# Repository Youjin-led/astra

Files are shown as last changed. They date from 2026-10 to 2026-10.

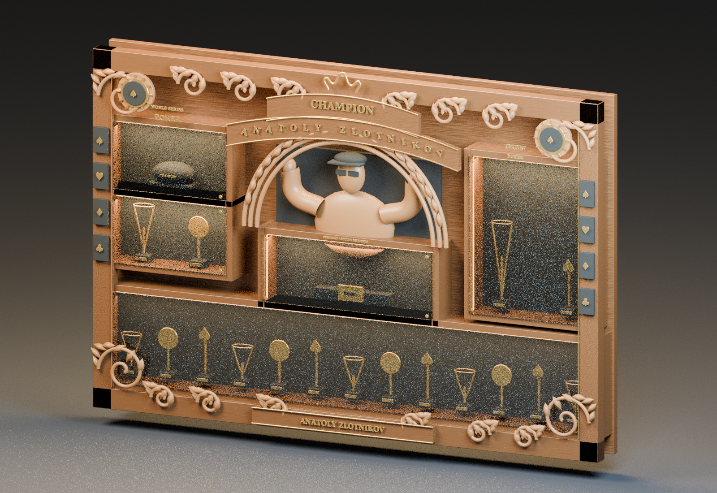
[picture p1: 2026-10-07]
design/astra_preview.png

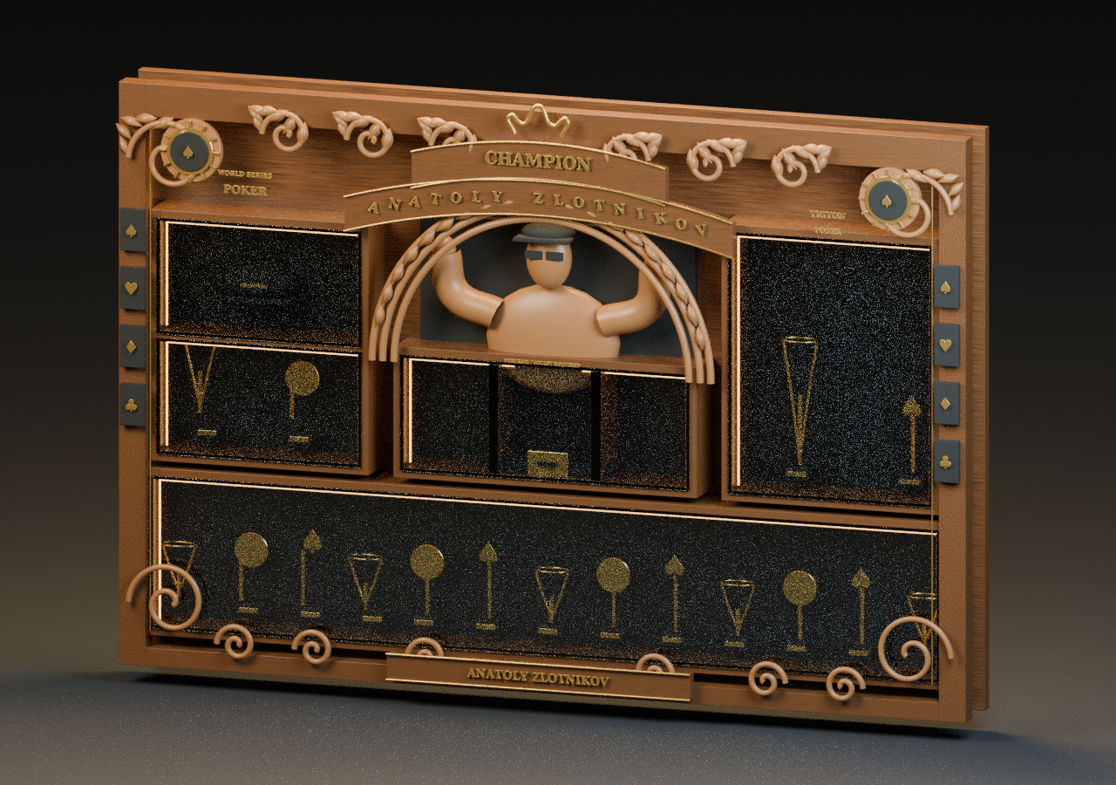
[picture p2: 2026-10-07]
project_v2/final_visual.png

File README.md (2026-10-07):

# ASTRA — витрина / инструкция по исходному референсу

Актуальная версия — инструкция с оригинальным изображением и его фрагментами из присланного ZIP:

- [Новый комплект — ZIP](https://github.com/Youjin-led/astra/raw/refs/heads/main/astra_reference_package.zip)
- [Новая инструкция — PDF, 24 страницы](https://github.com/Youjin-led/astra/raw/refs/heads/main/reference_project/assembly_from_reference_ru.pdf)
- [Описание и нерешённые размеры](reference_project/README.md)

Исходные размеры сохранены, включая нижнюю нишу 1160 × 200 мм. Для окончательного изготовления нужны уточнения, перечисленные в инструкции. Оригинальное изображение получено из ZIP и встроено: фасад, слои, детали и фрагменты для сборки.

---

## Архив предыдущей версии V2 (не актуальный образец внешнего вида)

## Скачать

- [Комплект для мастерской — ZIP](https://github.com/Youjin-led/astra/raw/refs/heads/main/astra_workshop_package.zip)
- [Инструкция сборки — PDF, 22 страницы](https://github.com/Youjin-led/astra/raw/refs/heads/main/project_v2/assembly_manual_ru.pdf)
- [Модель Blender с двумя сценами](https://github.com/Youjin-led/astra/raw/refs/heads/main/project_v2/astra_workshop_v2.blend)
- [Финальная визуализация](project_v2/final_visual.png)
- [Взрыв-схема слоёв](project_v2/exploded_layers.png)

В `project_v2` находятся спецификация 29 деталей, размерная разметка SVG/DXF, профили заготовок, раскрой и 11 этапов сборки. [Описание и ограничения версии](project_v2/README.md).

Это документация корпуса для прототипа. Перед окончательным раскроем нужны размеры экспонатов, подбор реальной фурнитуры и проверка крепления по стене и весу. Портрет, орнамент и надписи остаются эскизными; готовые траектории ЧПУ не включены. Нижний проём в V2 уменьшен до 1110 × 200 мм ради доступа к съёмной панели при общей ширине 1200 мм.

`design` содержит первую эскизную версию и материалы, используемые при воспроизведении V2.

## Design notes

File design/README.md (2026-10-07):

# ASTRA — эскиз витрины в Blender

Откройте `astra_display.blend` в Blender 4.3 или новее. `astra_preview.png` — рендер модели. `create_model.py` воспроизводит сцену командой:

```sh
blender -b -t 6 --python /workspace/astra/design/create_model.py
```

Единицы — миллиметры; координаты объектов в метрах. X — ширина, Z — высота, лицевая сторона направлена в −Y. Основная рама: 1200 × 800 мм. Корона выступает над ней примерно на 14 мм. Задняя панель 18 мм; внутренняя глубина ниш 70 мм; стенки коробов 15 мм; акрил 4 мм. Полная глубина с декоративными элементами около 120 мм: при выбранных толщинах уложиться в указанные на референсе 70–100 мм без переработки конструкции нельзя.

Коллекции разделяют заднюю панель, короба, декоративную резьбу, латунные надписи, акрил, LED, условные трофеи, условный портрет, крепление и студийную сцену. Объекты можно редактировать по отдельности. Орнамент процедурный; это интерпретация референса, а не точная копия.

Ниши: две левые 280 × 150 мм, центральная 400 × 150 мм, правая вертикальная 280 × 350 мм, нижняя 1160 × 200 мм. Правая вертикальная ниша объединена: референс неоднозначен в расположении правой средней секции. LED — визуализация тёплой подсветки, не электрическая схема. Акрил смоделирован прозрачным материалом с отдельными условными магнитами.

## Перед изготовлением

Это концептуальная модель, не готовые траектории ЧПУ или конструкторская документация. Портрет и экспонаты заменены объёмными заглушками. Для точного портрета нужны фотографии/скан; для посадки экспонатов — их размеры. Логотипы заменены текстовыми обозначениями. Для производства требуется уточнить орнамент, проверить замкнутость и технологичность деталей, радиусы фрез, зазоры, раскрой и прочность крепления. Указанная на картинке нагрузка 40–50 кг расчётом не подтверждена. Верхняя планка French cleat пока прямоугольная: угол и крепёж должны быть спроектированы отдельно.

Из-за перспективы и противоречий размеров на исходном изображении некоторые расположения выбраны эскизно. Надписи, ниши и детали должны быть согласованы перед выпуском рабочих файлов.

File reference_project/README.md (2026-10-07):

# ASTRA — инструкция по исходным изображениям

Эта версия создана заново по композиции и надписям на присланном референсе. Предыдущая модель Blender и размеры версии V2 не использованы.

## Файлы

- `assembly_from_reference_ru.pdf` — 24 страницы: исходные размеры, схема расположения, слои, перечень деталей, формулы коробов, узлы акрила / LED и 11 шагов сборки.
- `reference_dimensions.csv` — все шесть строк исходной таблицы размеров, открывается в Excel (UTF-8, разделитель `;`).
- `reference_dimensions.json` — сведения с изображения; неизвестные координаты оставлены пустыми.
- `reference_facade_preview.png` — предварительный просмотр страницы PDF с исходным фасадом.
- `measurements_template.csv` — бланк замеров экспонатов для мастера.
- `create_reference_manual.py` — генератор PDF; использует Python и ReportLab, без Blender.

Сохранены основной габарит 1200 × 800 мм и нижняя ниша 1160 × 200 × 70 мм. Стенки коробов 15–18 мм и слой дерева 30–40 мм оставлены как варианты исходного референса, а не произвольно выбранные толщины.

## Что ещё нужно для мастерской

Референс не содержит координат всех проёмов, отдельных размеров малых боковых ячеек, однозначного положения правой средней ниши, точного разреза, параметров магнитов, крепежа и рельефа. Поэтому это инструкция и размерное техническое задание, **не окончательная карта раскроя или готовая программа ЧПУ**. Уточнения перечислены на последней странице.

При отдельном накладном слое дерева указанная глубина 70–100 мм противоречит пакету материалов. Необходимо согласовать разрез до изготовления. Нагрузка крепления из референса не подтверждена.

## Исходные фотографии

Оригинальное изображение получено из ZIP пользователя и сохранено в `source/08387e1d-4358-4564-9a3d-56a1dc0bfdc0.png`. На обложку и страницу результата помещён фасад; в разделы сборки — соответствующие фрагменты коробов, декора, LED, магнитного узла и крепления на стену. На последней странице исходный лист показан целиком.

Изображение встроено в PDF как один оригинал; отдельные фрагменты показаны через области обрезки при вёрстке. Генеративная перерисовка и прежние Blender-рендеры не используются. Дополнительные схемы формул коробов, материалов и соединений оставлены плоскими пояснениями.

Исходный лист содержит визуализацию проекта, а не подтверждение изготовленного изделия. Пиксельные пропорции не используются как точные производственные размеры.

## Повторное создание

```sh
python /workspace/astra/reference_project/create_reference_manual.py
```

Шрифты DejaVu встраиваются в PDF, инструкция читается на Windows без установки шрифтов.

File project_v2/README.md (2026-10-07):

# ASTRA V2 — комплект для мастерской

Начните с **assembly_manual_ru.pdf**: 22 страницы, детали с номерами, размеры, раскрой, слои и 11 этапов сборки. В **astra_workshop_v2.blend** те же номера A/L/R/C/B/D/G. **final_visual.png** — финальная визуализация этой версии; **exploded_layers.png** — взрыв-схема. В Blender есть две сцены: собранный корпус и разделённые слои. **parts.csv** открывается в Excel, разделитель `;`, кодировка UTF-8 с BOM.

## Что переработано

В референсе размеры местами противоречат друг другу. V2 — самостоятельная компоновка по мотивам референса, согласованная между таблицей деталей и корпусом Blender:

- Рама 1200 × 800 мм. Корона выступает выше основной рамы; итоговая высота с декором больше 800 мм.
- Задник 18 мм; стенки 15 мм; чистая глубина до плоскости акрила 70 мм; акрил 4 мм.
- Левые проёмы 280 × 150 мм, два, общая полка.
- Правый проём 280 × 350 мм; отдельная правая средняя ниша не добавлена, поскольку в референсе её расположение неоднозначно.
- Центральный проём 400 × 150 мм с тремя ячейками 120 / 130 / 120 мм и двумя перегородками 15 мм.
- Нижний проём **1110 × 200 мм** вместо 1160 × 200 из референса. Это оставляет место для бокового декора и снятия акрила в раме шириной 1200 мм.
- Съёмные панели акрила накладные; нахлёст 5 мм. Боковые декоративные планки сужены до 38 мм. Между нижней панелью и планками номинально 2 мм с каждой стороны; проверить фактическую толщину/геометрию и зазоры до резки акрила.
- Базовый пакет 92 мм; выступающий декор и настенное крепление увеличивают общую глубину.

## Файлы для мастерской

`drawings/front_layout.svg` и `.dxf` — фронтальная разметка в миллиметрах, без траекторий резания и карты сверления. SVG содержит контрольную линейку 100 мм. Перед печатью/импортом проверить масштаб.

`drawings/*_blank.svg` — прямоугольные профили всех заготовок 1:1, **без отверстий, рельефа и технологических припусков**. Это не программы ЧПУ. Для деталей фанеры 15 мм показан широкий профиль полосы 70 мм.

`cut_plan.json` — раскрой полос 70 мм из листа 2440 × 1220 мм, расчётный пропил 3 мм. Пересчитать для фактической пилы и размера листа. `parts.json` — полный источник геометрии корпуса.

## Что нужно решить до изготовления

Комплект ещё **не утверждён для серийного или окончательного изготовления**. Сначала измерить экспонаты (особенно их глубину), выбрать породу дерева, реальные магниты/площадки и отделку, проверить прогиб длинной полки, утвердить крепёж по материалу стены и полному весу.

Резьба, портрет, логотипы, корона, надписи и трофеи — визуальные эскизы из первой модели. Их объекты помечены `CONCEPT`; они не входят в 29 прямоугольных деталей корпуса и не являются готовым комплектом ЧПУ. Орнаменты нужно переработать так, чтобы они не перекрывали снятие акрила и зоны крепежа. Нижняя резьба частично убрана из визуализации для доступа к нижней панели.

French cleat в Blender — схема расположения, а не проверенная пара сопряжённых деталей или расчёт крепежа. Две заготовки 1000 × 40 × 18 мм указаны отдельно в материалах; точный скос, сопряжение и анкеры определяет мастер после осмотра стены. Нагрузка 40–50 кг из картинки не подтверждена.

## Воспроизведение

Blender 4.3+, Python 3 с ReportLab. Запускать в существующей рабочей копии; отдельный worktree не нужен. Сохраните папку `design`: из неё загружаются исходные материалы и эскизный декор.

```sh
blender -b -t 6 --python /workspace/astra/project_v2/build_blender.py
blender -b /workspace/astra/project_v2/astra_workshop_v2.blend -t 6 --python /workspace/astra/project_v2/make_exploded.py
python /workspace/astra/project_v2/make_documents.py
python /workspace/astra/project_v2/validate_project.py
```

PDF генерируется после визуализации, чтобы новый рендер попал на обложку. Все размеры корпуса задаются в `project_data.py`.

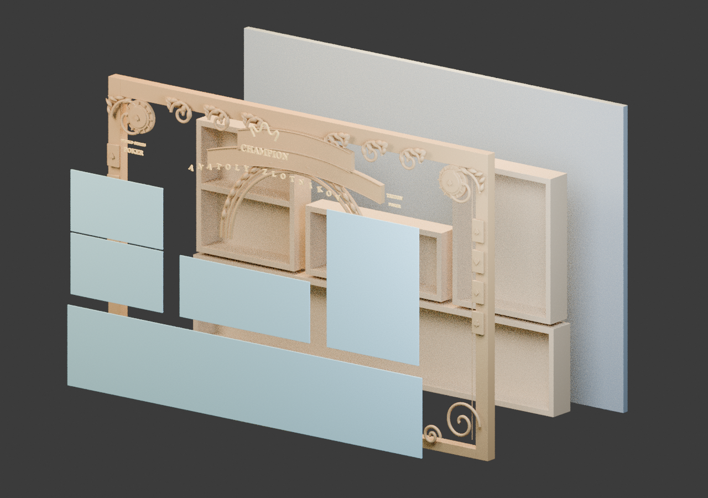
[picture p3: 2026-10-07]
project_v2/exploded_layers.png

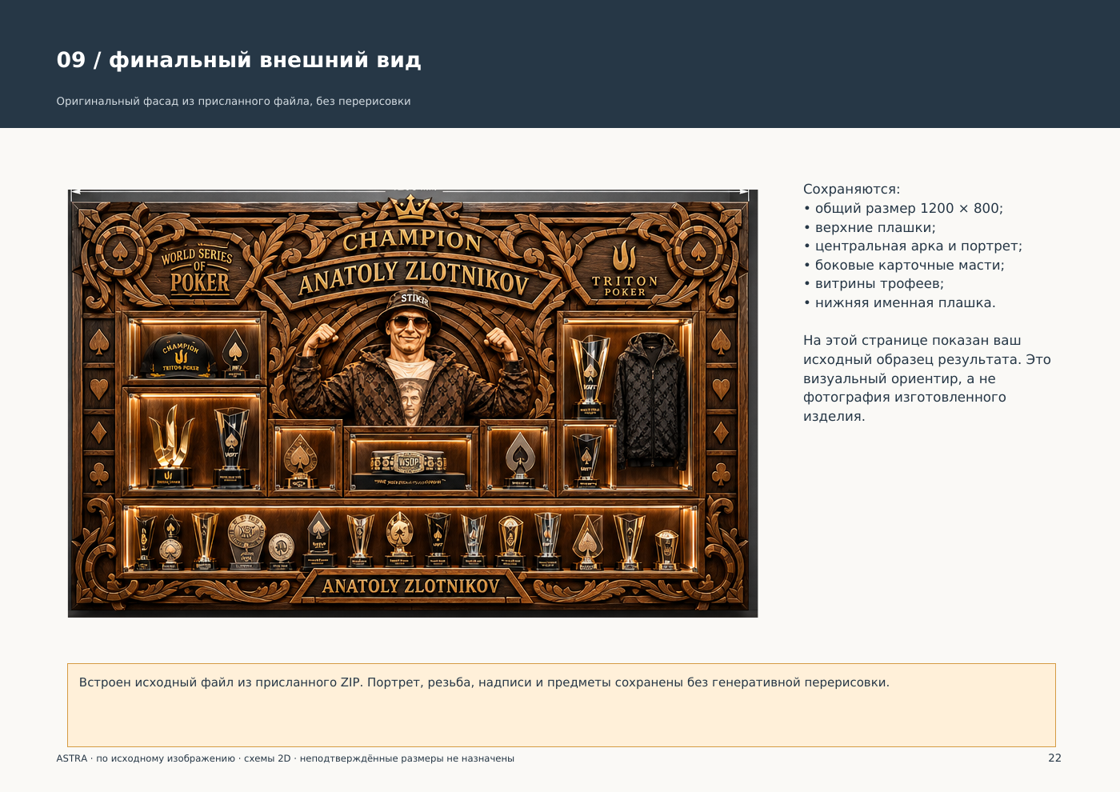
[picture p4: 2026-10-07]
reference_project/reference_facade_preview.png

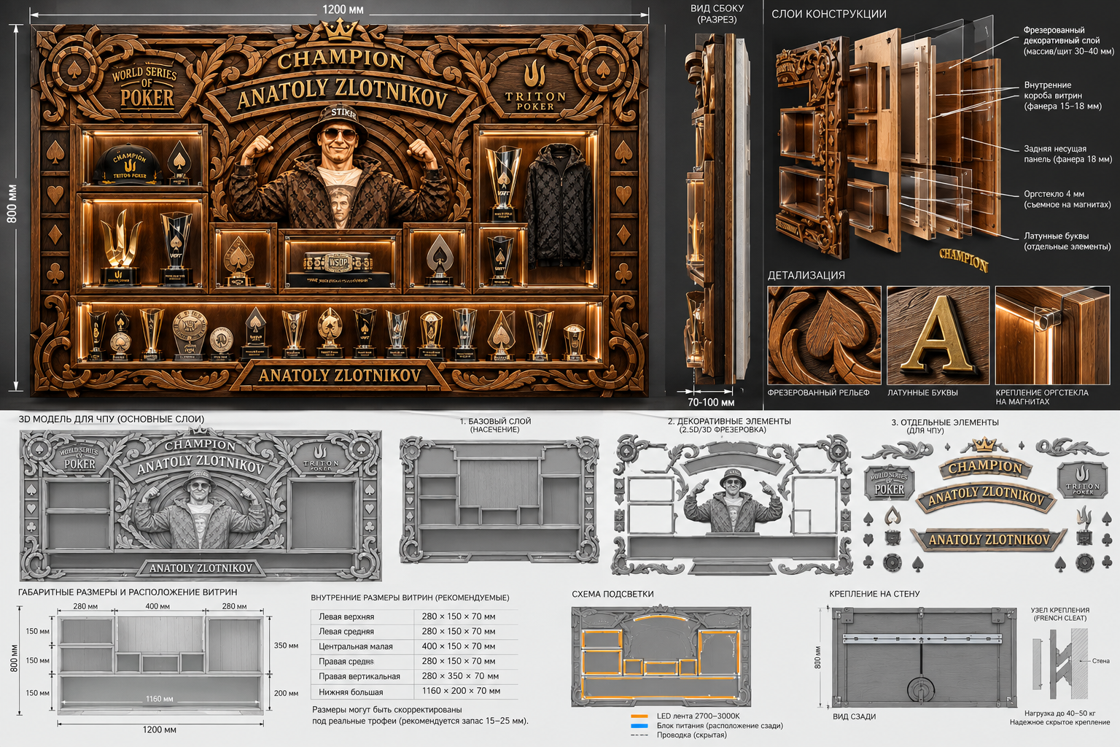
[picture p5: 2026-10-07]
reference_project/source/08387e1d-4358-4564-9a3d-56a1dc0bfdc0.png

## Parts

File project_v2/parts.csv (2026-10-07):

ID | Наименование | Материал | X мм | Y мм | Z мм | Центр X мм | Центр Y мм | Центр Z мм | Этап | Примечание
A01 | Задняя панель | Фанера 18 | 1200 | 18 | 800 | 0 | 9 | 400 | 1
L01 | Боковина левого блока | Фанера 15 | 15 | 70 | 345 | -552.5 | -35 | 452.5 | 2
L02 | Боковина левого блока | Фанера 15 | 15 | 70 | 345 | -257.5 | -35 | 452.5 | 2
L03 | Полка левого блока | Фанера 15 | 280 | 70 | 15 | -405 | -35 | 287.5 | 2
L04 | Полка левого блока | Фанера 15 | 280 | 70 | 15 | -405 | -35 | 452.5 | 2
L05 | Полка левого блока | Фанера 15 | 280 | 70 | 15 | -405 | -35 | 617.5 | 2
R01 | Боковина правого блока | Фанера 15 | 15 | 70 | 380 | 257.5 | -35 | 470 | 3
R02 | Боковина правого блока | Фанера 15 | 15 | 70 | 380 | 552.5 | -35 | 470 | 3
R03 | Полка правого блока | Фанера 15 | 280 | 70 | 15 | 405 | -35 | 287.5 | 3
R04 | Полка правого блока | Фанера 15 | 280 | 70 | 15 | 405 | -35 | 652.5 | 3
C01 | Боковина центрального блока | Фанера 15 | 15 | 70 | 180 | -207.5 | -35 | 370 | 4
C02 | Боковина центрального блока | Фанера 15 | 15 | 70 | 180 | 207.5 | -35 | 370 | 4
C03 | Полка центрального блока | Фанера 15 | 400 | 70 | 15 | 0 | -35 | 287.5 | 4
C04 | Полка центрального блока | Фанера 15 | 400 | 70 | 15 | 0 | -35 | 452.5 | 4
C05 | Перегородка центрального блока | Фанера 15 | 15 | 70 | 150 | -72.5 | -35 | 370 | 4
C06 | Перегородка центрального блока | Фанера 15 | 15 | 70 | 150 | 72.5 | -35 | 370 | 4
B01 | Боковина нижнего блока | Фанера 15 | 15 | 70 | 230 | -562.5 | -35 | 155 | 5
B02 | Боковина нижнего блока | Фанера 15 | 15 | 70 | 230 | 562.5 | -35 | 155 | 5
B03 | Полка нижнего блока | Фанера 15 | 1110 | 70 | 15 | 0 | -35 | 47.5 | 5 | Под нагрузкой проверить прогиб; при необходимости добавить опору.
B04 | Полка нижнего блока | Фанера 15 | 1110 | 70 | 15 | 0 | -35 | 262.5 | 5 | Под нагрузкой проверить прогиб; при необходимости добавить опору.
D01 | Боковая декоративная планка | Дерево 30 | 38 | 30 | 800 | -581 | -67 | 400 | 7 | Резьба эскизная; заготовка, не готовый рельеф ЧПУ.
D02 | Боковая декоративная планка | Дерево 30 | 38 | 30 | 800 | 581 | -67 | 400 | 7 | Резьба эскизная; заготовка, не готовый рельеф ЧПУ.
D03 | Нижняя декоративная планка | Дерево 30 | 1124 | 30 | 25 | 0 | -67 | 12.5 | 7
D04 | Верхняя декоративная планка | Дерево 30 | 1124 | 30 | 45 | 0 | -67 | 777.5 | 7
G01 | Левая нижняя панель | Акрил 4 | 290 | 4 | 160 | -405 | -72 | 370 | 8 | Накладная панель: нахлёст 5 мм на каждую сторону; проверить шаблоном.
G02 | Левая верхняя панель | Акрил 4 | 290 | 4 | 160 | -405 | -72 | 535 | 8 | Накладная панель: нахлёст 5 мм на каждую сторону; проверить шаблоном.
G03 | Центральная панель | Акрил 4 | 410 | 4 | 160 | 0 | -72 | 370 | 8 | Накладная панель: нахлёст 5 мм на каждую сторону; проверить шаблоном.
G04 | Правая панель | Акрил 4 | 290 | 4 | 360 | 405 | -72 | 470 | 8 | Накладная панель: нахлёст 5 мм на каждую сторону; проверить шаблоном.
G05 | Нижняя панель | Акрил 4 | 1120 | 4 | 210 | 0 | -72 | 155 | 8 | Накладная панель: нахлёст 5 мм на каждую сторону; проверить шаблоном.

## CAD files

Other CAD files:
project_v2/drawings/front_layout.dxf
design/astra_display.blend
project_v2/astra_workshop_v2.blend

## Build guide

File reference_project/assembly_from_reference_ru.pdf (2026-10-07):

## ASTRA / сборка по референсу

Оригинальное изображение, детали из референса и пошаговые пояснения

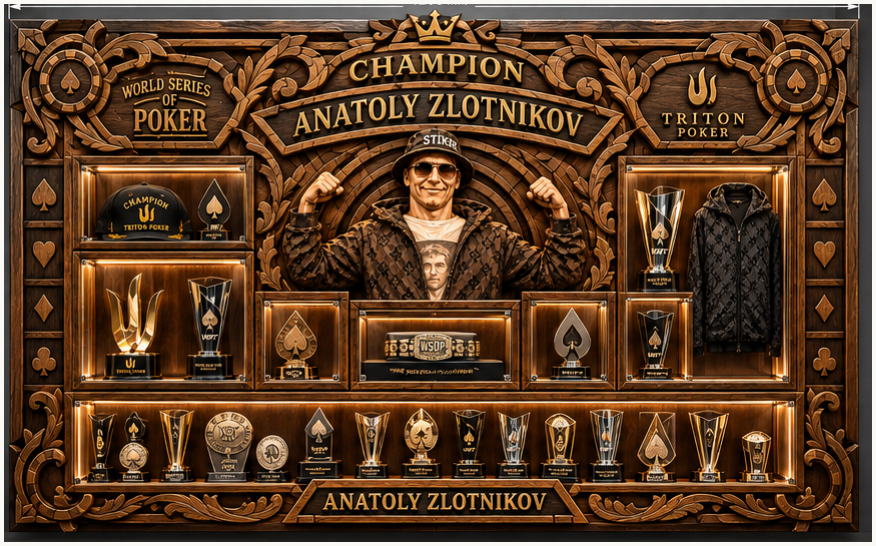
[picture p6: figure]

ASTRA · по исходному изображению · схемы 2D · неподтверждённые размеры не назначены | 1

В комплекте:
- исходные размеры;
- схема конструкции;
- перечень деталей;
- 11 этапов сборки;
- узлы акрила и LED.

Иллюстрации взяты из вашего файла. Резьба, портрет и
исходная композиция
сохранены. Дополнительные
схемы объясняют узлы сборки.

На обложке — фрагмент вашего исходного изображения. Разделение на детали показано далее теми же изображениями из референса.

## 01 / что зафиксировано на изображении

Миллиметры; сведения перенесены из исходного референса

ASTRA · по исходному изображению · схемы 2D · неподтверждённые размеры не назначены | 2
Параметр | Значение | Статус
Основной габарит | 1200 × 800 | Указано на изображении
Общая глубина | 70–100 | Указано; требует согласования слоёв
Задняя панель | Фанера 18 | Указано
Короба | Фанера 15–18 | Толщину нужно выбрать
Декоративный слой | Дерево / щит 30–40 | Указано; рельеф отдельно
Прозрачные панели | Акрил 4 | Указано
Надписи | Латунь, отдельные элементы | Толщина и контуры не заданы
Подсветка | LED 2700–3000 K | Питание и мощность не заданы
Настенное крепление | French cleat | Нагрузка и анкеры не подтверждены

Размер 1200 × 800 относится к основному прямоугольному корпусу. Включена ли выступающая корона в общий габарит — уточнить. Пропорции на картинке не заменяют координаты установки коробов и точные контуры резьбы.

## 02 / расположение витрин

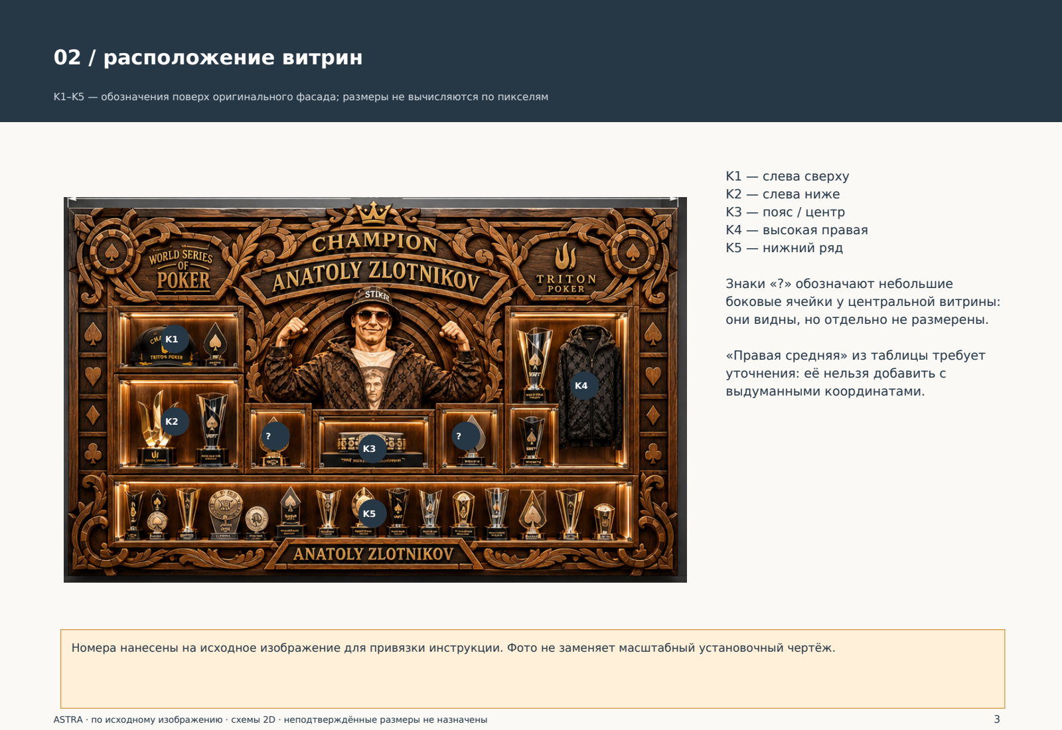
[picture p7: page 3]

K1–K5 — обозначения поверх оригинального фасада; размеры не вычисляются по пикселям

ASTRA · по исходному изображению · схемы 2D · неподтверждённые размеры не назначены | 3

K1

K2

K3

K4

K5

? | ?

K1 — слева сверху
K2 — слева ниже
K3 — пояс / центр
K4 — высокая правая
K5 — нижний ряд

Знаки «?» обозначают небольшие боковые ячейки у центральной витрины: они видны, но отдельно не размерены.

«Правая средняя» из таблицы требует уточнения: её нельзя добавить с выдуманными координатами.

Номера нанесены на исходное изображение для привязки инструкции. Фото не заменяет масштабный установочный чертёж.

## 03 / внутренние размеры из референса

Ширина × высота × глубина; шесть строк исходной таблицы сохранены

ASTRA · по исходному изображению · схемы 2D · неподтверждённые размеры не назначены | 4
Название | Размер, мм | Комментарий
Левая верхняя | 280 × 150 × 70 | Указано в таблице референса
Левая средняя | 280 × 150 × 70 | Указано в таблице референса
Центральная малая | 400 × 150 × 70 | Указано в таблице референса
Правая средняя | 280 × 150 × 70 | Положение не определено однозначно
Правая вертикальная | 280 × 350 × 70 | Указано в таблице референса
Нижняя большая | 1160 × 200 × 70 | Сохранено без уменьшения до 1110

Для реального изготовления сначала согласовать все видимые ячейки, их координаты и глубину предметов. Корпус с пятью визуальными группами и таблица с шестью нишами в референсе не согласованы полностью. Размеры неизвестных секций не назначены.

## 04 / слои конструкции

Оригинальная взрыв-схема из вашего изображения

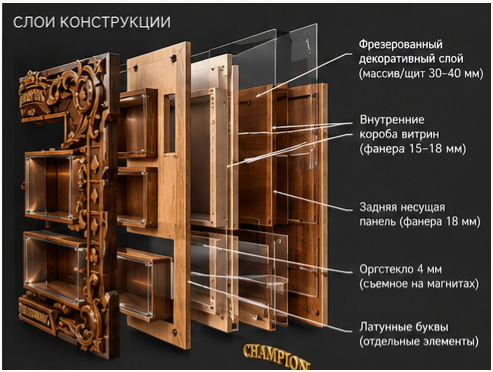
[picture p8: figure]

ASTRA · по исходному изображению · схемы 2D · неподтверждённые размеры не назначены | 5

Декоративный слой: дерево / щит 30–40 мм.

Короба: фанера 15–18 мм.

Задник: фанера 18 мм.

Акрил: 4 мм, съёмный.

Латунные надписи: отдельные элементы.

Сначала собирается несущий корпус. Декор, панели и надписи устанавливаются после примерки; акрил должен сниматься наружу.

## Детали / резьба, надписи и прозрачные панели

Увеличенные фрагменты вашего исходного изображения

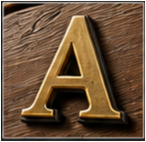
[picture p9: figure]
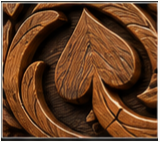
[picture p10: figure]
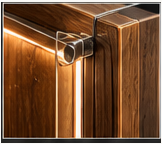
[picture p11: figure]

ASTRA · по исходному изображению · схемы 2D · неподтверждённые размеры не назначены | 6

Резной рельеф

Ориентир по рисунку и отделке дерева. Контур и глубина резьбы требуют отдельной подготовки.

Латунные буквы

Форма букв и сочетание с деревом — из референса. Толщина и способ крепления уточняются.

Узел оргстекла

Образец размещения прозрачной панели. Реальные магниты, площадки и зазоры подобрать пробой.

## 05 / перечень деталей и заготовок

Номера связывают инструкции; окончательный раскрой пока не утверждён

ASTRA · по исходному изображению · схемы 2D · неподтверждённые размеры не назначены | 7
ID | Деталь | Количество | Размер / требование
A | Несущая панель | 1 | 1200 × 800 × 18; до подтверждения крепления
K | Короба витрин | По согласованной схеме | Фанера 15 или 18; размерные формулы ниже
D | Резной фасад | Состав уточнить | Дерево / щит 30–40; по утверждённым контурам
P | Портретный рельеф | 1 | Фото / скан для отдельной модели рельефа
T | Арки, плашки, корона | По референсу | Контуры и габариты отдельно
G | Панели оргстекла | По числу проёмов | 4 мм; подгонка после сухой сборки
L | Латунные буквы / логотипы | Комплект | Шрифт, толщина, крепление согласуются
E | LED, профиль, провод, БП | Комплект | По длине и мощности выбранной ленты
M | Магниты и ответные элементы | По панелям | Количество и размер по пробе удержания
W | Планки и анкеры стены | Комплект | По весу изделия и типу стены

Трофеи, кепка, пояс и куртка на изображении — содержимое витрины, а не детали, которые требуется изготовить из дерева. Их нужно измерить и подобрать опоры.

## 06 / размеры стенок короба

Выбран простой короб без отдельной задней стенки: общим задником служит A

ASTRA · по исходному изображению · схемы 2D · неподтверждённые размеры не назначены | 8

Чистый проём W × H

t — выбранная толщина стенки

Деталь | Формула | Количество
Боковины | (H + 2t) × d × t | 2
Верх / низ | W × d × t | 2
Наружный габарит | (W + 2t) × (H + 2t) | —

Пример по исходной нише 280 × 150 × 70 при t=15: боковины 180 × 70 × 15; верх/низ 280 × 70 × 15. Наружный габарит 310 × 180. Это пример отдельного короба, не утверждённая карта сборки всех ниш.

Общие полки и стыковки соседних коробов требуют отдельного расчёта. Не суммировать автоматически отдельные короба: двойные стенки могут не поместиться.

## 07 / оргстекло и магнитный узел

Размеры панели определяются выбранным способом установки

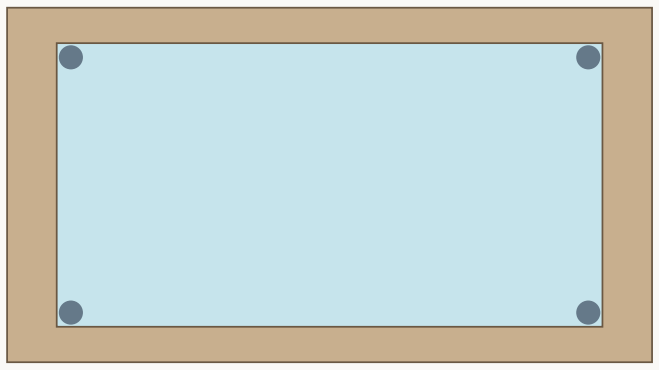
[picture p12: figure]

ASTRA · по исходному изображению · схемы 2D · неподтверждённые размеры не назначены | 9

Фасад: накладная панель

Снятие наружу

Накладная панель: размер проёма + два нахлёста. Нахлёст выбирается по размеру магнита, ответной площадки и декоративной рамке. Вставная панель: размер проёма минус монтажные зазоры; для неё требуется иной узел фиксации. Эти варианты не взаимозаменяемы.

Сначала картонный шаблон и пробный узел. Акрил 4 мм; не сверлить и не заказывать окончательные размеры до выбора фиксаторов и проверки снятия панели.

## 08 / LED и глубина

Схемы подключения низкого напряжения и размерная проверка

ASTRA · по исходному изображению · схемы 2D · неподтверждённые размеры не назначены | 10

Готовый блок DC

Левые ниши

Центр

Правая ниша

Нижний ряд

Ветви LED подключаются параллельно. Напряжение блока должно совпадать с лентой.

P = длина × Вт/м. Блок выбирать с запасом по инструкции оборудования. Длину и ток уточнить после утверждения ниш.

Сеть 220 В — только через готовый сертифицированный блок с доступом для обслуживания.

Проверка глубины: 18 мм задника + 70 мм короб + 4 мм акрил = 92 мм до декора. При добавлении слоя дерева 30–40 мм поверх пакета получится 122–132 мм, а не 70–100. Для сохранения меньшей глубины требуется согласованный разрез с перекрытием слоёв или изменение глубины ниш.

## Сборка / шаг 01

Согласовать рисунок и состав витрин

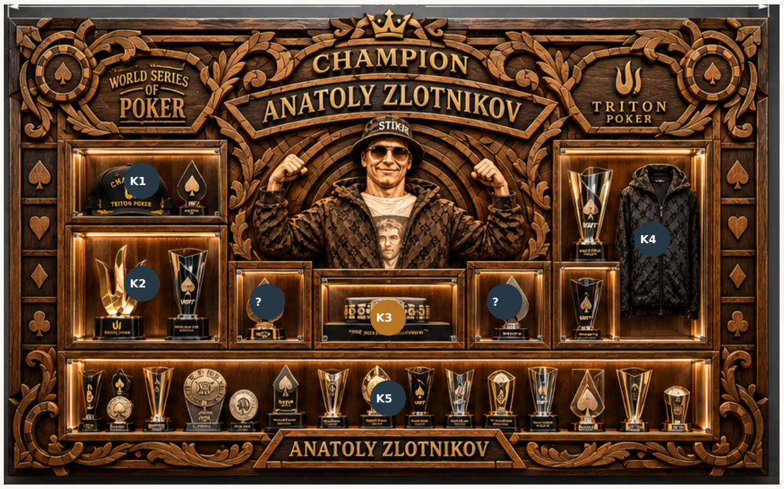
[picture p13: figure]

ASTRA · по исходному изображению · схемы 2D · неподтверждённые размеры не назначены | 11

Зафиксируйте исходную фотографию как образец финального внешнего вида. Утвердите положение всех ниш, включая правую среднюю и малые ячейки у пояса. Измерьте трофеи, кепку, пояс, куртку и их опоры.

Перед раскроем: известны все проёмы и координаты.

## Сборка / шаг 02

Подготовить материалы

ASTRA · по исходному изображению · схемы 2D · неподтверждённые размеры не назначены | 12
Фанера 18 / задник | Фанера 15–18 / короба
Дерево 30–40 / резьба | Акрил 4 / панели

Выберите фанеру 15 или 18 мм для коробов, задник 18 мм, дерево / щит 30–40 мм, акрил 4 мм. Измерьте фактические толщины. Отложите дефектные и покоробленные заготовки.

Перед раскроем: утверждены толщина, порода дерева и разрез.

## Сборка / шаг 03

Раскроить и разметить задник

ASTRA · по исходному изображению · схемы 2D · неподтверждённые размеры не назначены | 13

A — задняя панель 1200 × 800

Изготовьте A по согласованному габариту 1200 × 800. Проверьте прямые углы и диагонали. Перенесите контуры коробов и зоны крепления. Сверление выполняйте после сухой примерки, чтобы не переносить ошибки из фотографии.

Контроль: совпали габарит, диагонали и разметка.

## Сборка / шаг 04

Изготовить левые короба

ASTRA · по исходному изображению · схемы 2D · неподтверждённые размеры не назначены | 14

Рассчитайте боковины и полки по чистым размерам двух левых ниш. Выберите общую или раздельную среднюю полку. Сухая сборка → пробное сверление → склейка и крепёж → проверка угольником.

Контроль: оба чистых проёма проверены после сборки.

## Сборка / шаг 05

Изготовить остальные короба

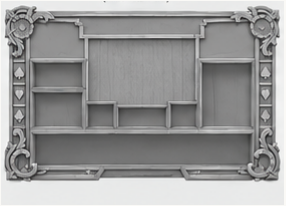
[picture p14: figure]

ASTRA · по исходному изображению · схемы 2D · неподтверждённые размеры не назначены | 15

Соберите центральную, правую и нижнюю группы. Нижний проём по референсу 1160 × 200 × 70. Малые боковые и правая средняя секции — только после уточнения схемы. Проверьте опирание длинной полки.

Контроль: экспонаты помещаются; нет двойных стенок и перекрытий.

## Сборка / шаг 06

Выполнить сухую сборку корпуса

ASTRA · по исходному изображению · схемы 2D · неподтверждённые размеры не назначены | 16

Положите задник на ровное основание, расставьте короба по утверждённой разметке, временно зафиксируйте. Примерьте декоративную рамку и картонные шаблоны прозрачных панелей. Только после проверки закрепите короба к A.

Контроль: декор не перекрывает снятие стекла и доступ к крепежу.

## Сборка / шаг 07

Изготовить резьбу по исходному рисунку

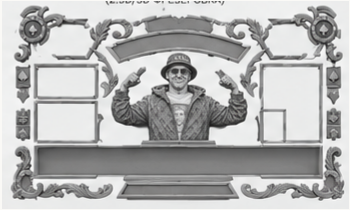
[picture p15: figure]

ASTRA · по исходному изображению · схемы 2D · неподтверждённые размеры не назначены | 17

Подготовьте контуры рамки, арки, короны, плашек и карточных мастей по референсу. Портрет выполняется отдельно по фотографиям / скану. Для ЧПУ мастер должен утвердить рельеф, фрезы, глубину и припуски; готовых траекторий в этом комплекте нет.

Контроль: пробная фрезеровка и утверждённый рельеф до дорогого дерева.

## Сборка / шаг 08

Подготовить поверхность и отделать

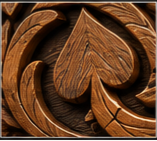
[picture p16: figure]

ASTRA · по исходному изображению · схемы 2D · неподтверждённые размеры не назначены | 18

Снимите заусенцы, отшлифуйте, выполните пробу цвета на обрезке. Отделайте корпус и декор, защитив места склейки и посадки магнитов. Дождитесь полного высыхания по инструкции состава.

Контроль: цвет согласован; покрытия и клеи совместимы.

## Сборка / шаг 09

Установить подсветку

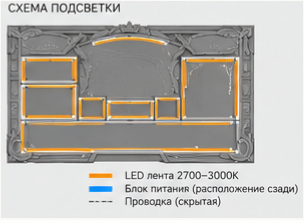
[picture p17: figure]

ASTRA · по исходному изображению · схемы 2D · неподтверждённые размеры не назначены | 19

Закрепите алюминиевые профили; нарежьте ленту только по
разрешённым меткам. Проложите провода с защитой проходов. Подключите ветви к подходящему готовому блоку питания и проверьте освещение, нагрев и доступ для обслуживания.

Контроль: электрические параметры подтверждены выбранными изделиями.

## Сборка / шаг 10

Подогнать прозрачные панели

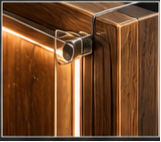
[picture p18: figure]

ASTRA · по исходному изображению · схемы 2D · неподтверждённые размеры не назначены | 20

Примерьте шаблоны, определите нахлёсты / зазоры, затем изготовьте панели G. Установите магниты и ответные площадки по пробному узлу. Проверьте удержание, возможность снятия и отсутствие контакта с предметами.

Контроль: каждая панель снимается без разборки декора.

## Сборка / шаг 11

Завершить сборку и закрепить на стене

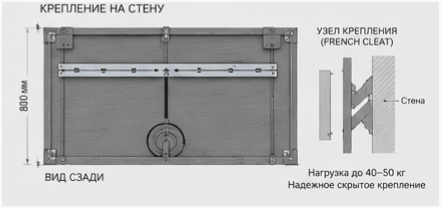
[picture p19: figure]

ASTRA · по исходному изображению · схемы 2D · неподтверждённые размеры не назначены | 21

Установите латунные буквы, логотипы и готовые декоративные детали. Подберите French cleat и анкеры под стену и фактический полный вес. С помощником закрепите изделие, установите экспонаты и выполните итоговую проверку.

Контроль: несущая схема проверена; доступ к питанию и панелям сохранён.

## 09 / финальный внешний вид

Оригинальный фасад из присланного файла, без перерисовки

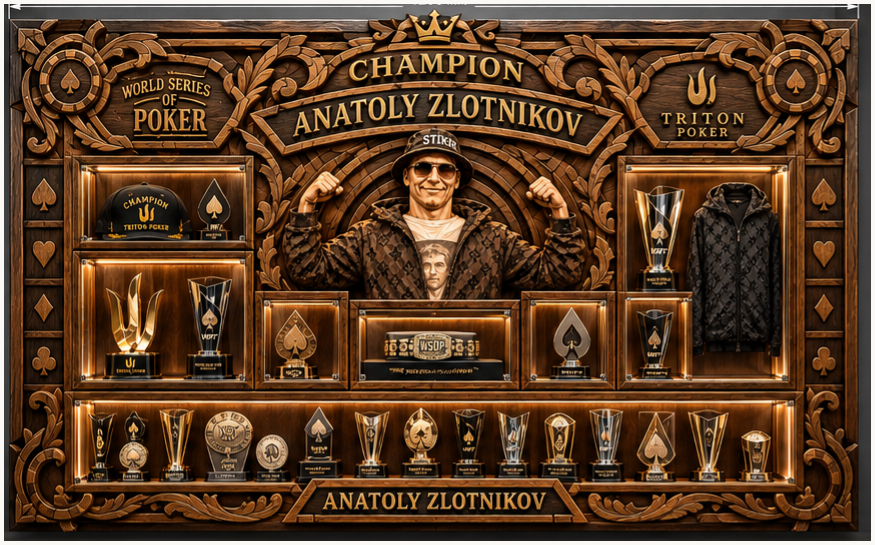
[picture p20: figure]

ASTRA · по исходному изображению · схемы 2D · неподтверждённые размеры не назначены | 22

Сохраняются:
- общий размер 1200 × 800;
- верхние плашки;
- центральная арка и портрет;
- боковые карточные масти;
- витрины трофеев;
- нижняя именная плашка.

На этой странице показан ваш исходный образец результата. Это визуальный ориентир, а не
фотография изготовленного
изделия.

Встроен исходный файл из присланного ZIP. Портрет, резьба, надписи и предметы сохранены без генеративной перерисовки.

## 10 / до передачи в окончательное изготовление

Список нерешённых размеров и узлов вместо выдуманных деталей

ASTRA · по исходному изображению · схемы 2D · неподтверждённые размеры не назначены | 23
Размещение | Координаты всех ниш; правая средняя; малые боковые ячейки; общий габарит с короной.
Экспонаты | Габариты и вес всех предметов; особенно куртки, кепки и основания кубков при глубине 70 мм.
Материалы | Толщина коробов 15 или 18; порода дерева, влажность, отделка, припуски и направление волокон.
Глубина | Согласованный разрез: референс 70–100 мм против пакета 92 мм без добавочного декора.
Панели | Схема установки акрила, реальные магниты и площадки, нахлёст / зазор и доступ для снятия.
Резьба | Утверждённые контуры и рельеф портрета; толщина латунных деталей; отдельный CAM.
Стена | Тип стены, масса изделия с экспонатами, проверка анкеров, French cleat и прогиба полок.

Комплект объясняет путь от заготовок до результата. Окончательные карты раскроя и сверления выпускаются после закрытия перечисленных пунктов.

## Приложение / исходный лист целиком

Ваш загруженный файл: все виды, надписи и схемы сохранены


ASTRA · по исходному изображению · схемы 2D · неподтверждённые размеры не назначены | 24

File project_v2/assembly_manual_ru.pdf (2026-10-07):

# ASTRA / инструкция по сборке

Корпус из фанеры, декоративное дерево, съёмный акрил и подсветка


ASTRA · V2 · мм · Документация прототипа; резьба и крепление требуют доработки | 1

1200 × 800 мм — основная рама Глубина коробов 70 мм
Задник 18 мм; стенки 15 мм
Акрил 4 мм

Комплект содержит чертежи, список деталей, раскрой и 11 шагов сборки.

Это рабочий эскиз корпуса для прототипа. Производственный рельеф и расчёт креплений в комплект не входят.

Объекты с пометкой CONCEPT в Blender не являются готовыми деталями для ЧПУ.

# 01 / фасад и чистые проёмы

Координаты: X — от центра; Z — от нижней кромки A01; Y — глубина

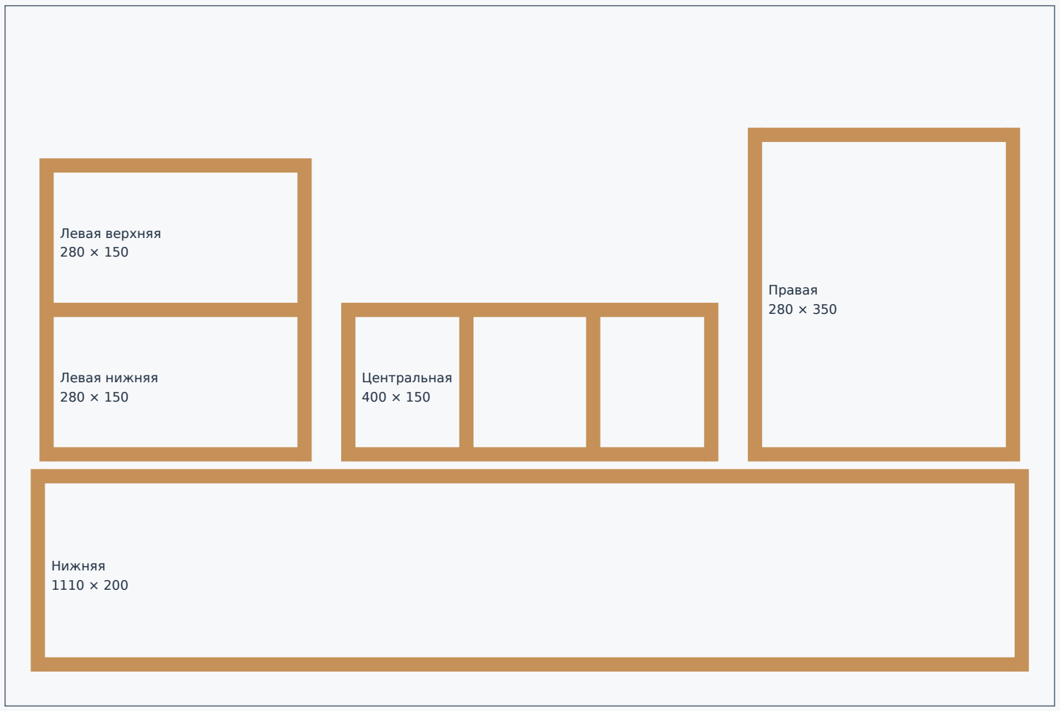
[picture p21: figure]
Левая нижняя 280 × 150; Левая верхняя 280 × 150; Центральная 400 × 150; Правая 280 × 350; Нижняя 1110 × 200

ASTRA · V2 · мм · Документация прототипа; резьба и крепление требуют доработки | 2

1200

800

Внутренние размеры ниш
указаны без стенок.

Две левые ниши имеют
общую полку.

Центр разделён на 120 /
130 / 120 мм.

Правая ниша одна, 280 ×
350 мм.

Отдельная «правая
средняя» секция из
таблицы референса не
добавлена: её положение
не определено.

# 02 / глубина и слои

Разрез условный, не в масштабе; лицевая сторона слева

ASTRA · V2 · мм · Документация прототипа; резьба и крепление требуют доработки | 3
Декор / буквы | Акрил 4 Короба 70 | A01 / 18 | Крепление

Базовый пакет задник + короб + акрил = 18 + 70 + 4 = 92 мм. Накладной декор, буквы и рельеф выступают дальше; фактическую полную глубину измерять по финальным деталям. Крепление добавляет зазор от стены. Корона выходит за номинальную высоту 800 мм примерно на 14 мм.

Декоративные планки 30 мм установлены с перекрытием края коробов, а не добавлены целиком поверх акрила. Панели должны сниматься без демонтажа декора.

# Слои / взрыв-схема

Вынос деталей условный; синий слой обозначает прозрачный акрил


ASTRA · V2 · мм · Документация прототипа; резьба и крепление требуют доработки | 4

A01 — задняя панель
L / R / C / B — короба
D — декоративная рама
CONCEPT — резьба и буквы
G01–G05 — акрил

Портрет, трофеи и настенное крепление скрыты для ясности. На схеме панели показаны
непрозрачными, чтобы было видно разделение слоёв.

# 03 / деревянные детали

Длины заготовок окончательные для показанного корпуса; размеры резьбы уточняются отдельно

ASTRA · V2 · мм · Документация прототипа; резьба и крепление требуют доработки | 5
ID | Деталь | Материал | X × Y × Z, мм | Центр X; Z
A01 | Задняя панель | Фанера 18 | 1200 × 18 × 800 | 0; 400
L01 | Боковина левого блока | Фанера 15 | 15 × 70 × 345 | -552.5; 452.5
L02 | Боковина левого блока | Фанера 15 | 15 × 70 × 345 | -257.5; 452.5
L03 | Полка левого блока | Фанера 15 | 280 × 70 × 15 | -405; 287.5
L04 | Полка левого блока | Фанера 15 | 280 × 70 × 15 | -405; 452.5
L05 | Полка левого блока | Фанера 15 | 280 × 70 × 15 | -405; 617.5
R01 | Боковина правого блока | Фанера 15 | 15 × 70 × 380 | 257.5; 470
R02 | Боковина правого блока | Фанера 15 | 15 × 70 × 380 | 552.5; 470
R03 | Полка правого блока | Фанера 15 | 280 × 70 × 15 | 405; 287.5
R04 | Полка правого блока | Фанера 15 | 280 × 70 × 15 | 405; 652.5
C01 | Боковина центрального блока | Фанера 15 | 15 × 70 × 180 | -207.5; 370
C02 | Боковина центрального блока | Фанера 15 | 15 × 70 × 180 | 207.5; 370
C03 | Полка центрального блока | Фанера 15 | 400 × 70 × 15 | 0; 287.5
C04 | Полка центрального блока | Фанера 15 | 400 × 70 × 15 | 0; 452.5
C05 | Перегородка центрального блока | Фанера 15 | 15 × 70 × 150 | -72.5; 370
C06 | Перегородка центрального блока | Фанера 15 | 15 × 70 × 150 | 72.5; 370
B01 | Боковина нижнего блока | Фанера 15 | 15 × 70 × 230 | -562.5; 155
B02 | Боковина нижнего блока | Фанера 15 | 15 × 70 × 230 | 562.5; 155
B03 | Полка нижнего блока | Фанера 15 | 1110 × 70 × 15 | 0; 47.5
B04 | Полка нижнего блока | Фанера 15 | 1110 × 70 × 15 | 0; 262.5

# 04 / декор и акрил

Длины заготовок окончательные для показанного корпуса; размеры резьбы уточняются отдельно

ASTRA · V2 · мм · Документация прототипа; резьба и крепление требуют доработки | 6
ID | Деталь | Материал | X × Y × Z, мм | Центр X; Z
D01 | Боковая декоративная планка | Дерево 30 | 38 × 30 × 800 | -581; 400
D02 | Боковая декоративная планка | Дерево 30 | 38 × 30 × 800 | 581; 400
D03 | Нижняя декоративная планка | Дерево 30 | 1124 × 30 × 25 | 0; 12.5
D04 | Верхняя декоративная планка | Дерево 30 | 1124 × 30 × 45 | 0; 777.5
G01 | Левая нижняя панель | Акрил 4 | 290 × 4 × 160 | -405; 370
G02 | Левая верхняя панель | Акрил 4 | 290 × 4 × 160 | -405; 535
G03 | Центральная панель | Акрил 4 | 410 × 4 × 160 | 0; 370
G04 | Правая панель | Акрил 4 | 290 × 4 × 360 | 405; 470
G05 | Нижняя панель | Акрил 4 | 1120 × 4 × 210 | 0; 155

Акрил накладной: +10 мм к ширине и высоте чистого проёма. Нахлёст 5 мм с каждой стороны. Между двумя левыми панелями остаётся зазор 5 мм. Заготовки декора D01–D04 не описывают арку, портрет и отдельные узоры: эти элементы требуют собственного комплекта моделей после согласования.

# 05 / материалы и раскрой

Распил по фактической толщине материала; не использовать толщину из этикетки без замера

ASTRA · V2 · мм · Документация прототипа; резьба и крепление требуют доработки | 7

Полоса 1: ширина 70 мм

B03 / 1110 | B04 / 1110 | C01 / 180

Полоса 2: ширина 70 мм

C03 / 400 | C04 / 400 | R01 / 380 | R02 / 380 | L01 / 345 | L02 / 345 | C05 / 150

Полоса 3: ширина 70 мм

L03 / 280 | L04 / 280 | L05 / 280 | R03 / 280 | R04 / 280 | B01 / 230 | B02 / 230 | C02 / 180 | C06 / 150

Фанера 15 мм: 3 полосы 2440 × 70 мм из одного листа 2440 × 1220, пропил 3 мм; остаток сохраняется. Это линейный план по длине, не программа станка. Фанера 18 мм: A01 1200 × 800 из отдельной заготовки. Дерево 30 мм: 2 шт. 800 × 38; 1124 × 25 и 1124 × 45; запас на отделку и орнамент — отдельно. French cleat: 2 заготовки 1000 × 40 × 18, скос 45° проектируется по месту.

# 06 / разметка задней панели

Для переноса в мастерскую используйте drawings/front_layout.svg или front_layout.dxf

ASTRA · V2 · мм · Документация прототипа; резьба и крепление требуют доработки | 8

1200

800

Блок | Левый низ X; Z | Габарит с боковинами
Левый | 40; 280 | 310 × 345
Правый | 850; 280 | 310 × 380
Центр | 385; 280 | 430 × 180
Нижний | 30; 40 | 1140 × 230

Здесь X указан от левого края A01, Z — от нижнего.

В таблице деталей X указан от центра: прибавьте 600.

Сначала сухая сборка, затем сверление. Разметка не является утверждённой картой отверстий под крепёж.

# 07 / LED и съёмный акрил

Магниты и блок питания сначала проверить на отдельном пробном узле

ASTRA · V2 · мм · Документация прототипа; резьба и крепление требуют доработки | 9

1200

800

LED сверху и по двум бокам каждого проёма: суммарно 4,35 м без припуска.

Пример: 12 В, 9,6 Вт/м → 41,76 Вт. С запасом 25% нужен блок ≥52,2 Вт; пример выбора — 60 Вт. Пересчитать по выбранной ленте.

Пять ветвей подключаются
параллельно к 12 В. Сетевую часть использовать готовую,
сертифицированную; не собирать её внутри деревянного корпуса.

Провода проложить скрыто, с защитой кромок отверстий и разгрузкой натяжения. Доступ к блоку питания оставить сзади. Магниты: 20 шт. и 20 стальных площадок; окончательный диаметр, глубина гнезда и клей — по выбранному изделию и пробе удержания.

# 08 / соединения и закупка

Выполнить пробный узел перед сверлением и склейкой готовых деталей

ASTRA · V2 · мм · Документация прототипа; резьба и крепление требуют доработки | 10
Позиция | Количество / требование
Шурупы 3,5 × 35 | Ориентировочно 100 шт.; уточнить схему и пробное сверление
Столярный клей | По материалу и условиям; выдержка по инструкции
Магниты + стальные площадки | 20 + 20; Ø4 в модели — только пример, не спецификация покупки
Акрил | 4 мм; 5 отдельных панелей по G01–G05
LED + алюминиевый профиль | 4,35 м чистой длины; купить с припуском, резать по меткам
Блок питания | Готовый 12 В / 60 Вт для примера ленты 9,6 Вт/м
Провод, клеммы, защита проходов | По току каждой ветви, длине и инструкции оборудования
Крепёж стены / French cleat | Выбрать после определения стены и полного веса

Узел задника: головка снаружи A01 → 18 мм фанеры → торец 15-мм стенки короба. Шуруп 35 мм входит в стенку на 17 мм. Ось сверления — середина толщины стенки. Для крепления к A01 ориентир — шаг не более 150 мм, от концов не менее 30 мм; окончательно по пробе материала и нагрузке.

Узел акрила: накладная панель с нахлёстом 5 мм → приклеенная ответная стальная площадка → утопленный в кромку дерева магнит. Площадка и клей имеют толщину: уточнить фактическое положение панели. Если выбранный магнит не помещается в 15-мм кромке, нужен отдельный держатель и новая деталировка.

Не затягивать шуруп в торец фанеры без пробного сверления. Несущая способность не рассчитана.

# Сборка / шаг 01

Проверить размеры и изготовить заготовки

ASTRA · V2 · мм · Документация прототипа; резьба и крепление требуют доработки | 11
Фанера 18 → A01 | Фанера 15 → полосы 70
Дерево 30 → декор | Акрил 4 → G01–G05

Сначала материалы и заготовки — затем сухая сборка. Проверьте реальные размеры экспонатов. Разметьте детали по спецификации. Раскройте фанеру с учётом ширины пропила, дерево — с припуском на обработку. Акрил пока оставьте в защитной плёнке.

Оранжевым выделены добавляемые детали; вынос вперёд условный.

Инструмент: пила с направляющей, угольник, рулетка, струбцины, дрель, пробные свёрла, шлифование; ЧПУ требуется для точного рельефа.

# Сборка / шаг 02

Подготовить заднюю панель A01

ASTRA · V2 · мм · Документация прототипа; резьба и крепление требуют доработки | 12

A01

Лицевая сторона панели — плоскость Y=0. Начало размеров: нижний левый угол. Перенесите координаты коробов с листа разметки. Наметьте крепление и трассы провода; сначала проверьте заготовки сухой сборкой.

Детали этого шага: A01

Оранжевым выделены добавляемые детали; вынос вперёд условный.

# Сборка / шаг 03

Собрать левый блок L01–L05

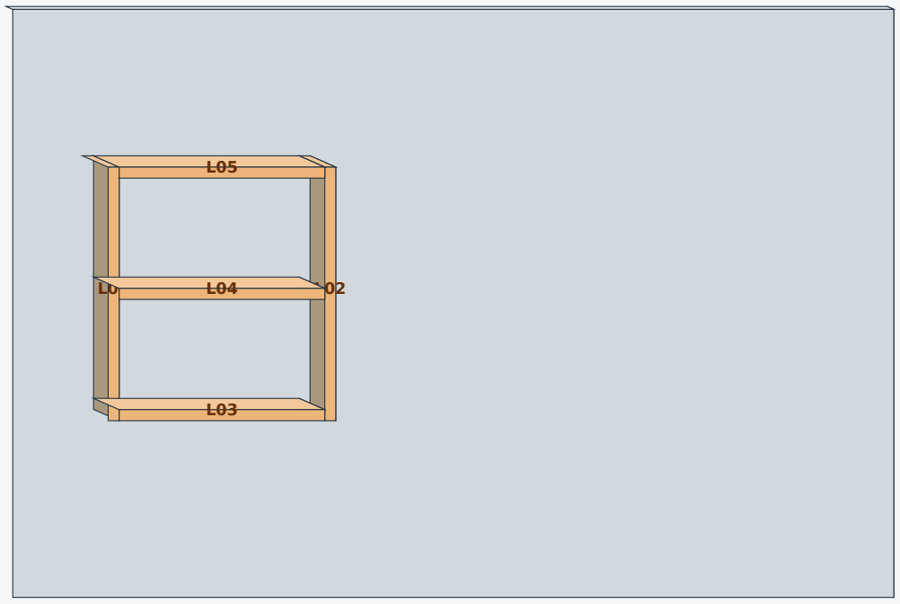
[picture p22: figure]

ASTRA · V2 · мм · Документация прототипа; резьба и крепление требуют доработки | 13

Между боковинами поставьте три полки. Нижний чистый проём 280×150; верхний также 280×150. L04 — общая полка. Проверьте диагонали; соедините столярным клеем и подходящим крепежом после пробного сверления.

Детали этого шага: L01, L02, L03, L04, L05

Оранжевым выделены добавляемые детали; вынос вперёд условный.

# Сборка / шаг 04

Собрать правый блок R01–R04

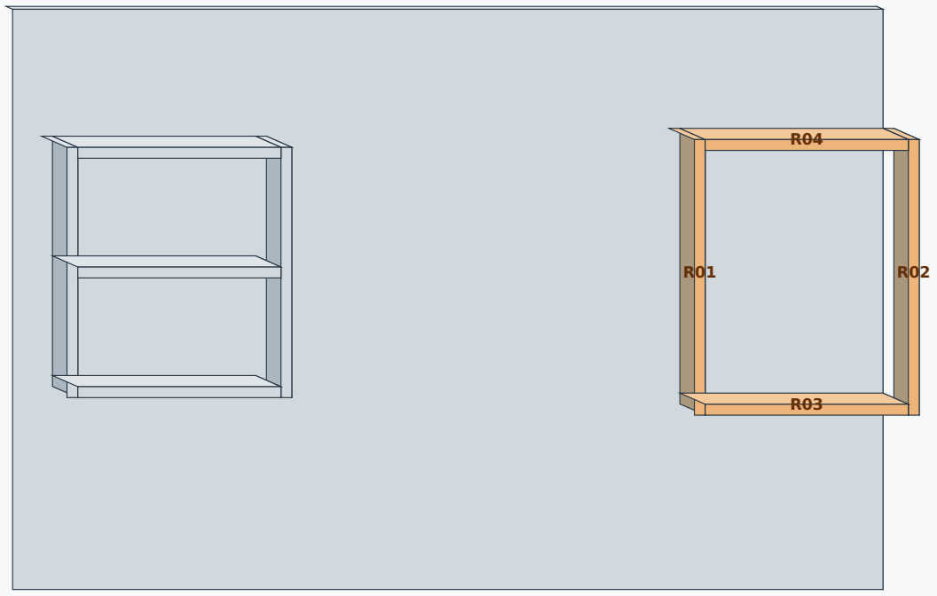
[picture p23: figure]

ASTRA · V2 · мм · Документация прототипа; резьба и крепление требуют доработки | 14

Поставьте две боковины и две полки. Чистый проём 280×350. Установите блок на заднюю панель по координатам, а не по декоративной раме.

Детали этого шага: R01, R02, R03, R04

Оранжевым выделены добавляемые детали; вынос вперёд условный.

# Сборка / шаг 05

Собрать центральный блок C01–C06

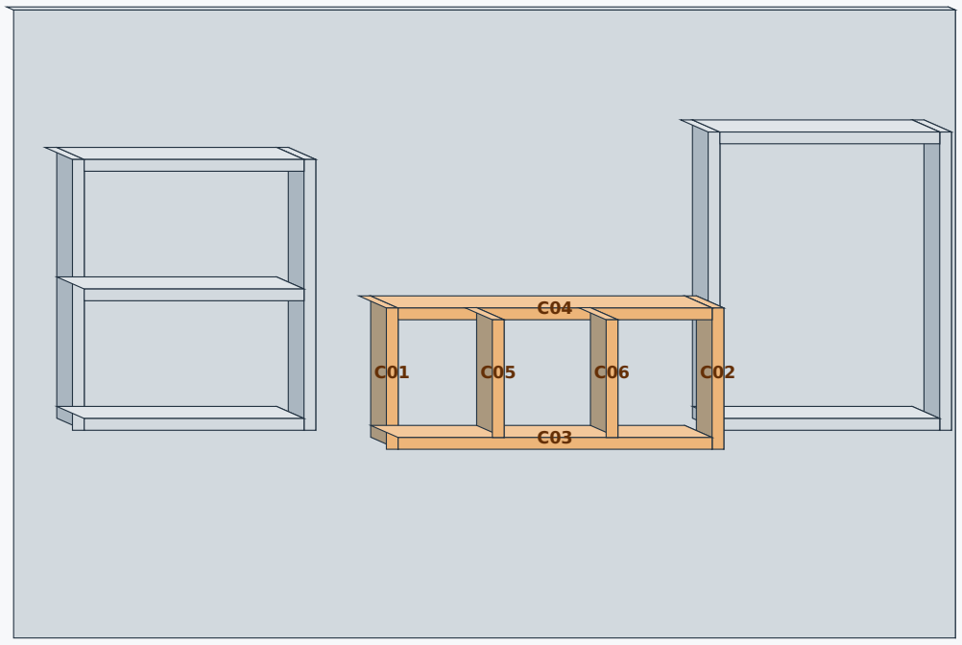
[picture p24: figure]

ASTRA · V2 · мм · Документация прототипа; резьба и крепление требуют доработки | 15

Сначала корпус с чистым проёмом 400×150, затем перегородки C05/C06. Получатся три ячейки шириной 120 / 130 / 120 мм. Перегородки идут от задника до лицевой кромки.

Детали этого шага: C01, C02, C03, C04, C05, C06

Оранжевым выделены добавляемые детали; вынос вперёд условный.

# Сборка / шаг 06

Собрать нижний блок B01–B04

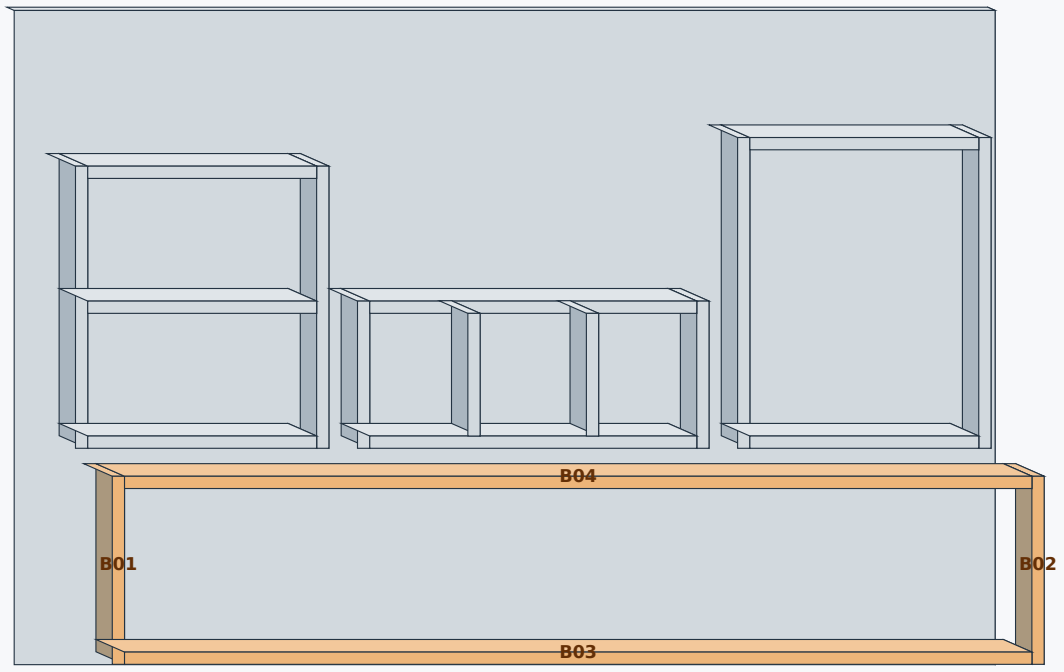
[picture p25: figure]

ASTRA · V2 · мм · Документация прототипа; резьба и крепление требуют доработки | 16

Чистый проём 1110×200. Склейте и выровняйте блок; закрепите к A01. Длинная нижняя полка должна иметь опору на задник. Проверьте прогиб с фактическими экспонатами до монтажа стекла.

Детали этого шага: B01, B02, B03, B04

Оранжевым выделены добавляемые детали; вынос вперёд условный.

# Сборка / шаг 07

Закрепить блоки, отделать и подключить LED

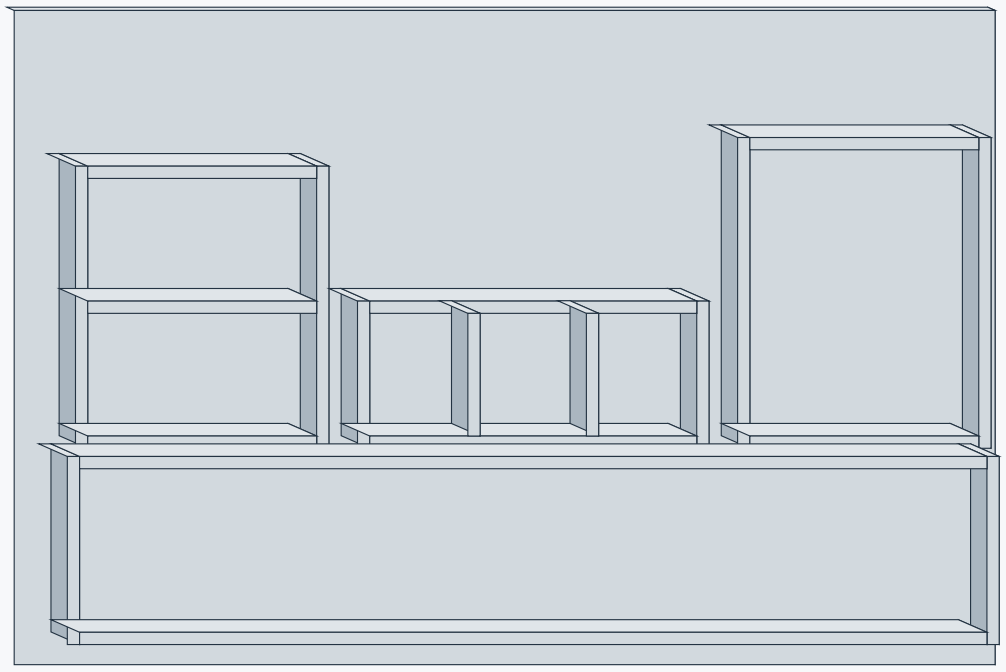
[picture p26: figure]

ASTRA · V2 · мм · Документация прототипа; резьба и крепление требуют доработки | 17

Пример крепления к A01: шуруп 3,5×35 через задник в середину 15-мм стенки. Сверлить направляющие отверстия по пробе материала; головки утопить без разрушения шпона. Покройте дерево совместимым составом, дождитесь полного высыхания, затем закрепите LED в алюминиевых профилях.

Оранжевым выделены добавляемые детали; вынос вперёд условный.

# Сборка / шаг 08

Установить декор и надписи

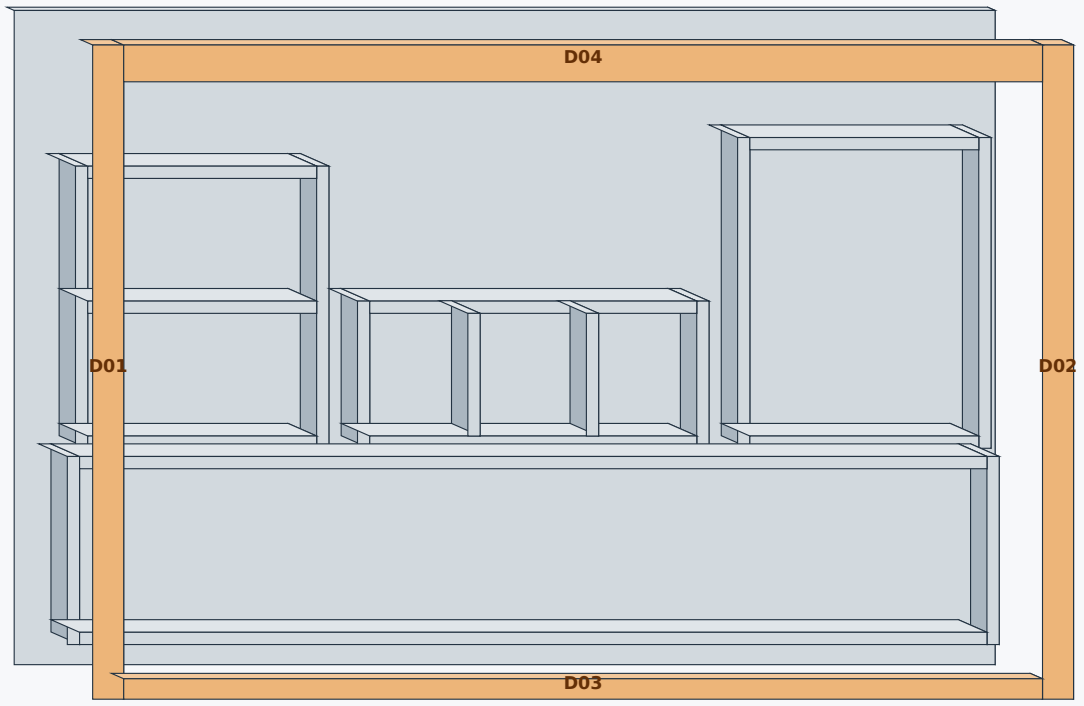
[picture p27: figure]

ASTRA · V2 · мм · Документация прототипа; резьба и крепление требуют доработки | 18

D01/D02 по краям; D03/D04 между ними. Сначала сухая примерка. Рельеф, арка, портрет и латунные буквы — отдельные детали, пока эскизные. Декор не должен перекрывать снятие G01–G05 или доступ к проводке.

Детали этого шага: D01, D02, D03, D04

Оранжевым выделены добавляемые детали; вынос вперёд условный.

# Сборка / шаг 09

Подогнать акрил и магнитные фиксаторы

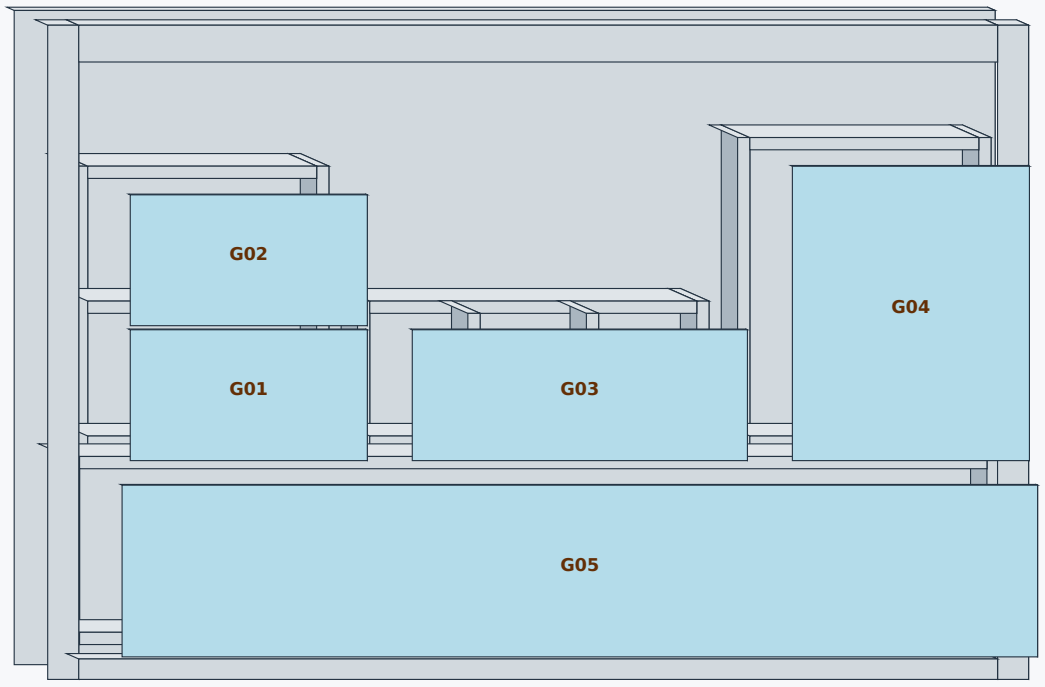
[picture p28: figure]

ASTRA · V2 · мм · Документация прототипа; резьба и крепление требуют доработки | 19

Панели накладные, нахлёст 5 мм. Примерьте картонные шаблоны. По четыре магнита на панель — в древесине, ответные стальные площадки приклеены к акрилу. Размер и силу магнитов подобрать на пробном узле. Не сверлите акрил по неподтверждённому шаблону.

Детали этого шага: G01, G02, G03, G04, G05

Оранжевым выделены добавляемые детали; вынос вперёд условный.

# Сборка / шаг 10

Сделать заднее крепление и контрольную сборку

ASTRA · V2 · мм · Документация прототипа; резьба и крепление требуют доработки | 20

1200

800

W01 — планка корпуса, схема сзади

W02 крепится к стене. Угол 45° и сопряжение — по месту.

French cleat — пара планок со скосом 45°. Подберите крепёж под стену и полный вес изделия; расчёт нагрузки здесь не выполнен. Установку выполняйте с помощником. Проверьте отсутствие люфта, удержание панелей и возможность обслуживания блока питания.

Оранжевым выделены добавляемые детали; вынос вперёд условный.

# Сборка / шаг 11

Расставить экспонаты и проверить результат

ASTRA · V2 · мм · Документация прототипа; резьба и крепление требуют доработки | 21

Установите реальные предметы, включите подсветку и проверьте нагрев. Проверьте, что ни одна панель не касается экспонатов и каждая снимается безопасно. Сохраните уточнённые размеры и фотографии готовой сборки.

Оранжевым выделены добавляемые детали; вынос вперёд условный.

# 09 / перед запуском в изготовление

Контрольный лист мастера — обязательные решения, которые нельзя получить из картинки

ASTRA · V2 · мм · Документация прототипа; резьба и крепление требуют доработки | 22
Экспонаты | Записать ширину, высоту, глубину и вес каждого предмета. Глубина 70 мм может не вместить куртку, кепку
| и основания кубков.
Дерево и толщина | Указать породу, влажность, фактическую толщину фанеры, отделку. Проверить крепёж на обрезке,
| направление волокон и прочность длинной полки.
Рельеф для ЧПУ | Нужны отдельные утверждённые модели портрета, арки, логотипов и резьбы; выбрать фрезы и радиусы.
| Кривые в Blender не заменяют готовый CAM.
Магниты и акрил | Выбрать фиксаторы, клей и способ снятия панелей; проверить сколы, удержание и зазоры на прототипе.
Стена и нагрузка | Определить материал стены и полный вес. Проверить несущие крепления и профиль French cleat; нагрузка
| 40–50 кг из референса не подтверждена.
Финальный контроль | Проверить геометрию, прогиб, устойчивость, нагрев LED, отсутствие острых кромок и обслуживание. Только
| после этого утверждать проект.

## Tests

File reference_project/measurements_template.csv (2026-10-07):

Предмет | Ширина мм | Высота мм | Глубина мм | Вес кг | Примечание
Кепка |  |  |  |  | Замерить вместе с основанием / опорой
Куртка в выбранной форме размещения |  |  |  |  | Замерить вместе с основанием / опорой
Пояс |  |  |  |  | Замерить вместе с основанием / опорой
Самый крупный кубок |  |  |  |  | Замерить вместе с основанием / опорой
Остальные кубки / медали |  |  |  |  | Замерить вместе с основанием / опорой

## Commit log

2026-10-07 Add Blender display cabinet concept and downloadable model
    [astra_display.blend]
2026-10-07 Add dimensioned V2 cabinet project and illustrated assembly manual
    [astra_workshop_v2.blend, front_layout.dxf, parts.csv]
2026-10-07 Add 2D assembly guide based on original reference dimensions
    [measurements_template.csv, reference_dimensions.csv]
2026-10-07 Embed original reference image and detail crops in assembly manual
